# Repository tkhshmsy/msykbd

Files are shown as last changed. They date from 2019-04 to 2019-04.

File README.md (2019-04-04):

# msykbd

tkhshmsy's original keyboard which contains pcb, chassis, and firmware

## why build this?

I have been using [Logitech G13](https://support.logitech.com/en_us/product/g13-advanced-gameboard) which is very good and my favorite one.

With long use, it became not to working properly...
So, I want NEW one, but, unfortunately, G13 was already discontinued production.

I decided to make it myself.

## product

- Left-hand Gaming Keypad
  - 35 Keys
  - AnalogStick (work as keys, not pointing device)

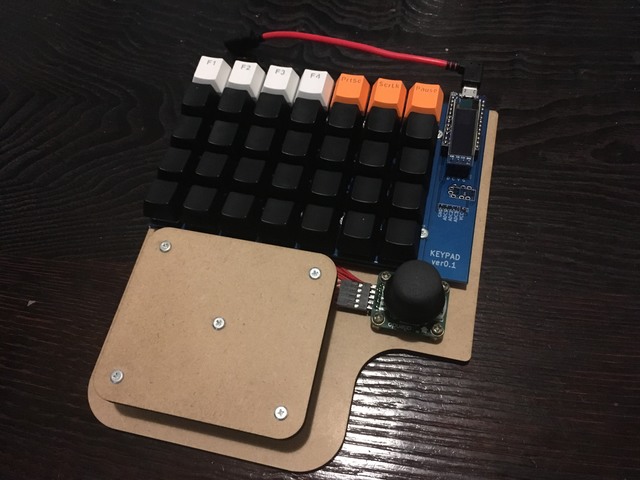
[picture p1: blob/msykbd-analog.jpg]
keypad


- Separate Ortholinear Keyboard
  - US 70 keys

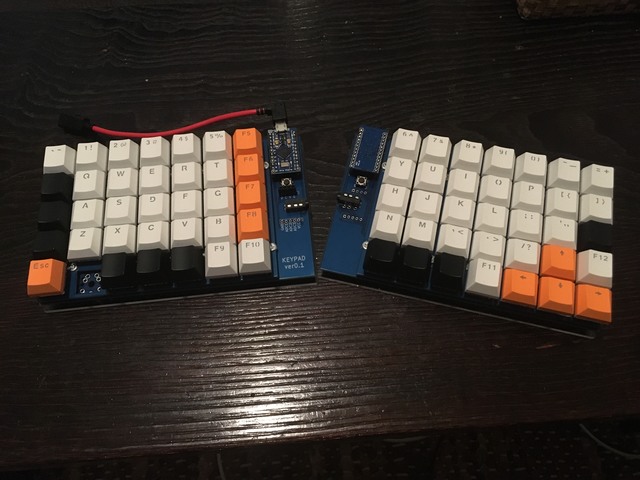
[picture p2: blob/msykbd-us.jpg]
uskbd

 
## PCB

- designed with Kicad v5

### parts

- promicro (ATMega32U4@16MHz)
- OLED (128x32 with SSD1306)
- mechanical key switches
  - cherryMX or Kailh Lowprofile
- TRRS plug
  
## Firmware

- build with platformio
  - framework : arduino

### required libraries

- ID 891
  - Keyboard
- ID 13
  - Adafruit GFX
- ID 135
  - Adafruit SSD1306

## Chassis

- designed with Fusion360
  - export DXF and convert into Adobe Illustrator
- for LaserCutter 'trotec Speedy 300'
  - worked at [FabLab Setagaya at IID](http://fablabsetagaya.com/)

## Author

- tkhshmsy@gmail.com

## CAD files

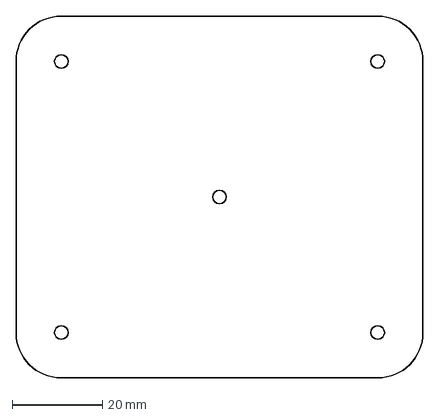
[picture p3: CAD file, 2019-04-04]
chassis/msykbd_parmrest_analog5x7.dxf
90.0 x 80.0 mm

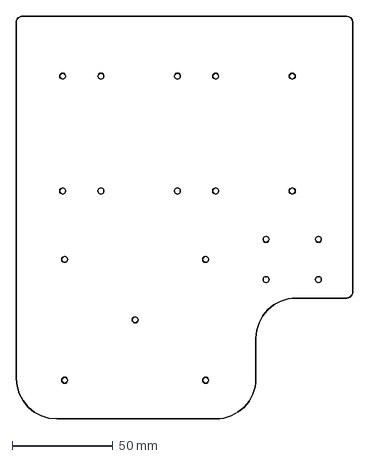
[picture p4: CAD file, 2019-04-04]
chassis/msykbd_analog5x7.dxf
167.0 x 200.0 mm

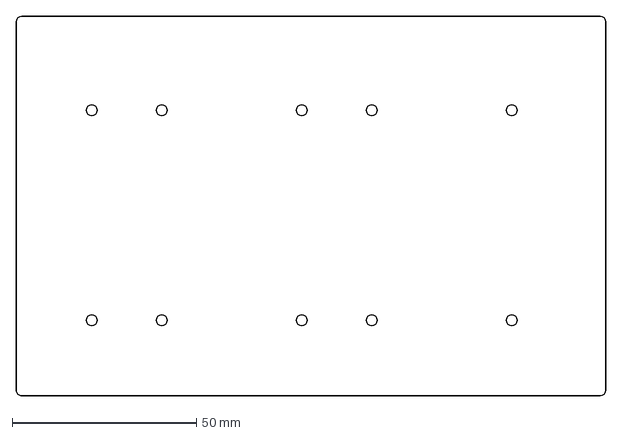
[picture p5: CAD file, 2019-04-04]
chassis/msykbd_base5x7.dxf
160.0 x 103.0 mm

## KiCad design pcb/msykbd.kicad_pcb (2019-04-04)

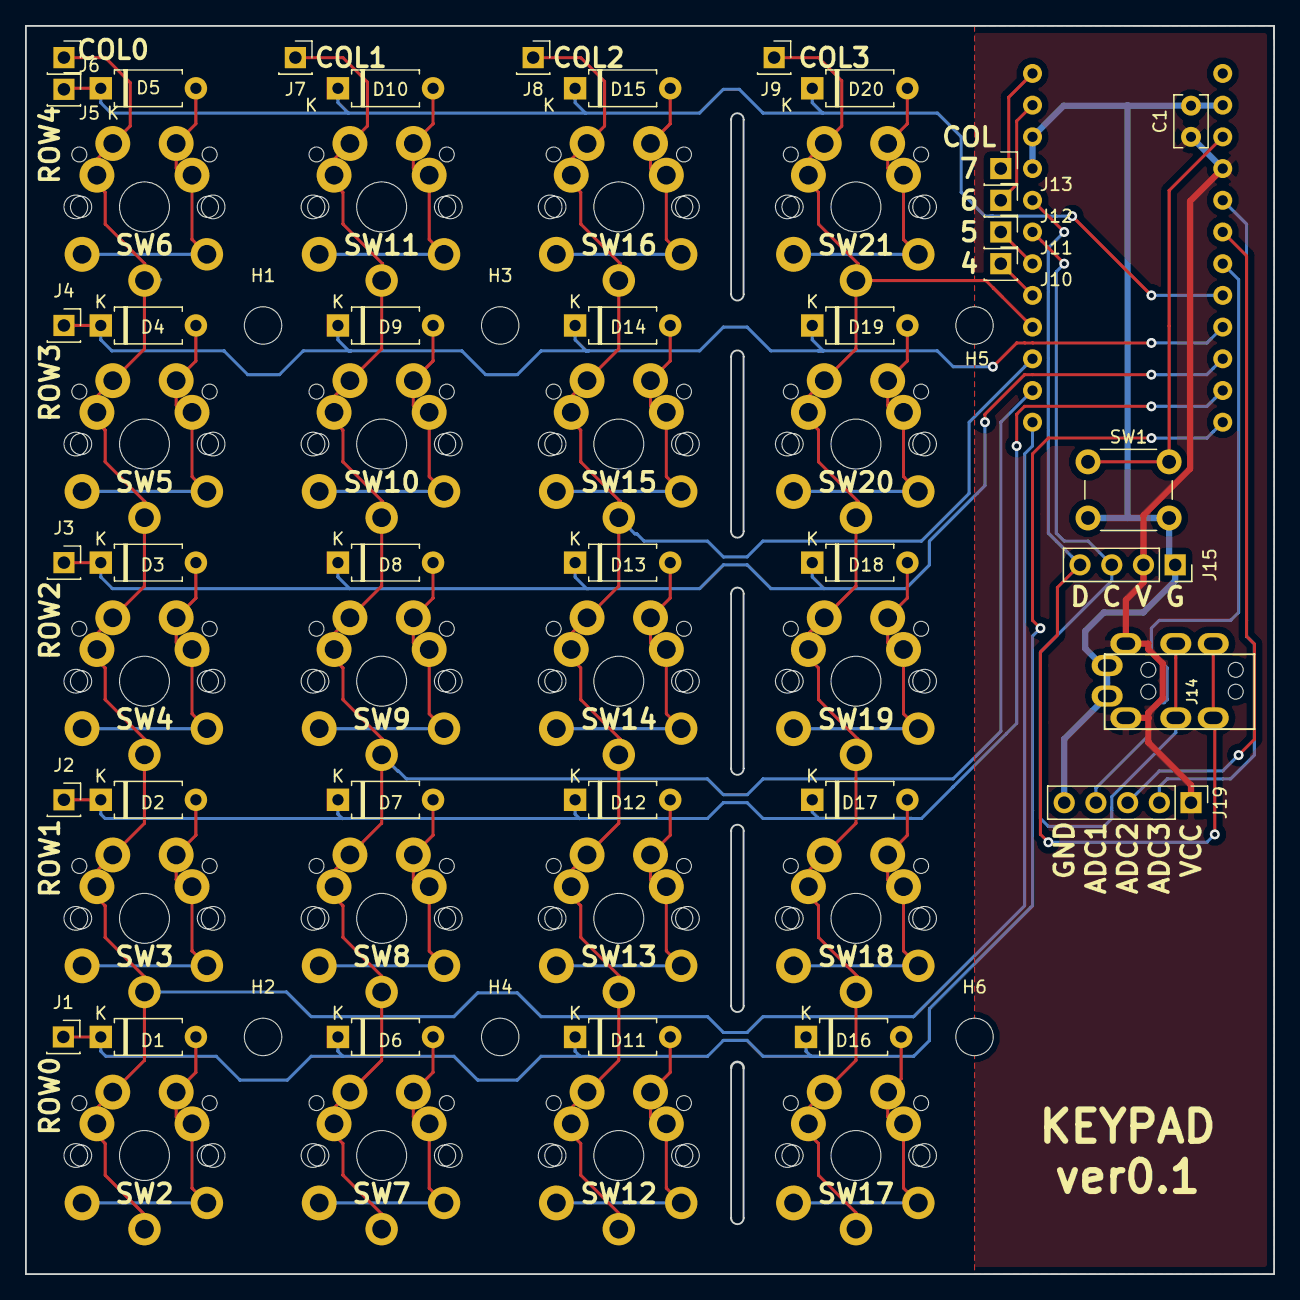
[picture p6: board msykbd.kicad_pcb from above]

Board: 2 copper layers, 100.0 x 100.0 mm, 65 parts (0 on the bottom side), 41 nets.

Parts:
C1: C_Small; C_Rect_L4.0mm_W2.5mm_P2.50mm
D1, D2, D3, D4, D5, D6, D7, D8, D9, D10, D11, D12, D13, D14, D15, D16, D17, D18, D19, D20: D; D_A-405_P7.62mm_Horizontal
H1, H2, H3, H4, H5, H6: MountingHole; MountingHole_3mm
J1, J2, J3, J4, J5, J6, J7, J8, J9, J10, J11, J12, J13: Conn_01x01; PinSocket_1x01_P2.54mm_Vertical
J14: MJ-4PP-9; MJ-4PP-9_rev2
J15: Conn_01x04; PinSocket_1x04_P2.54mm_Vertical
J19: Conn_01x05; PinHeader_1x05_P2.54mm_Vertical
SW1: SW_Push; SW_PUSH_6mm
SW2, SW3, SW4, SW5, SW6, SW7, SW8, SW9, SW10, SW11, SW12, SW13, SW14, SW15, SW16, SW17, SW18, SW19, SW20, SW21: SW_Push; MX_PG1350-Under_FLIP_HOLES_
U1: ProMicro; ProMicro_rev

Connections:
+5V: C1.1, J14.D, J15.2, J19.1, U1.21
/ADC1: J19.4, U1.18
/ADC2: J19.3, U1.19
/ADC3: J19.2, U1.20
/COL0: J6.1, SW2.1, SW3.1, SW4.1, SW5.1, SW6.1, U1.12
/COL1: J7.1, SW7.1, SW8.1, SW9.1, SW10.1, SW11.1, U1.11
/COL2: J8.1, SW12.1, SW13.1, SW14.1, SW15.1, SW16.1, U1.10
/COL3: J9.1, SW17.1, SW18.1, SW19.1, SW20.1, SW21.1, U1.9
/COL4: J10.1, U1.8
/COL5: J11.1, U1.7
/COL6: J12.1, U1.2
/COL7: J13.1, U1.1
/ROW0: D1.1, D6.1, D11.1, D16.1, J1.1, U1.13
/ROW1: D2.1, D7.1, D12.1, D17.1, J2.1, U1.14
/ROW2: D3.1, D8.1, D13.1, D18.1, J3.1, U1.15
/ROW3: D4.1, D9.1, D14.1, D19.1, J4.1, U1.16
/ROW4: D5.1, D10.1, D15.1, D20.1, J5.1, U1.17
/SCL: J14.C, J15.3, U1.6
/SDA: J14.B, J15.4, U1.5
/nRST: SW1.1, U1.22
GND: C1.2, J14.A, J15.1, J19.5, SW1.2, U1.3, U1.4, U1.23
unnamed: D1.2, SW2.2
unnamed: D2.2, SW3.2
unnamed: D3.2, SW4.2
unnamed: D4.2, SW5.2
unnamed: D5.2, SW6.2
unnamed: D6.2, SW7.2
unnamed: D7.2, SW8.2
unnamed: D8.2, SW9.2
unnamed: D9.2, SW10.2
unnamed: D10.2, SW11.2
unnamed: D11.2, SW12.2
unnamed: D12.2, SW13.2
unnamed: D13.2, SW14.2
unnamed: D14.2, SW15.2
unnamed: D15.2, SW16.2
unnamed: D16.2, SW17.2
unnamed: D17.2, SW18.2
unnamed: D18.2, SW19.2
unnamed: D19.2, SW20.2
unnamed: D20.2, SW21.2

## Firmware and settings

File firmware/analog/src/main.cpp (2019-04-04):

#include <Arduino.h>
#include <Keyboard.h>
#include <Wire.h>

#include "globals.h"
#include "keymatrix.h"
#include "oled.h"
#include "analogstick.h"

// #define FOR_DEBUG

KeyMatrix keyMatrix;
AnalogStick analogStick;
OLED oled;
uint8_t keyStates[COLUMNS];
int currentLayer = 1;
int nextLayer = 0;
int waitingLayer = nextLayer;
int waitingCounter = 0;

int rowPins[ROWS] = {
    18, 15, 14, 16, 10
};

int columnPins[COLUMNS] = {
    1, 6, 7, 8, 9, 5, 4, 0
};

uint8_t keyMap[LAYERS][ALLROWS][COLUMNS] = {
    { //defualt : PSO2
        {KC_DFLT,  KC_RAISE, KC_LOWER, KC_MEDIA, KC_PRSCN, KC_F1,    KC_F8,   KC_NONE}, 
        {KC_I,     KC_D,     KC_ESC,   KC_SPC,   KC_X,     KC_N,     KC_n8,   KC_NONE},
        {KC_U,     KC_R,     KC_LSHT,  KC_Q,     KC_E,     KC_ENTER, KC_n7,   KC_NONE},
        {KC_n9,    KC_n1,    KC_n2,    KC_n3,    KC_n4,    KC_n5,    KC_n6,   KC_NONE},
        {KC_G,     KC_B,     KC_F11,   KC_n0,    KC_F12,   KC_F5,    KC_F6,   KC_NONE},
        {KC_A,     KC_P,     KC_S,     KC_W,     KC_Z,     KC_NONE,  KC_NONE, KC_NONE}
    },
    { //raise
        {KC_DFLT,  KC_RAISE, KC_LOWER, KC_MEDIA, KC_PRSCN, KC_F1,    KC_F8,   KC_NONE}, 
        {KC_TAB,   KC_Q,    KC_W,    KC_E,    KC_R,   KC_T,     KC_NONE, KC_NONE},
        {KC_LCTR,  KC_A,    KC_S,    KC_D,    KC_F,   KC_G,     KC_NONE, KC_NONE},
        {KC_LSHT,  KC_Z,    KC_X,    KC_C,    KC_V,   KC_B,     KC_NONE, KC_NONE},
        {KC_RAISE, KC_NONE, KC_LALT, KC_LGUI, KC_SPC, KC_LOWER, KC_NONE, KC_NONE},
        {KC_A,     KC_D,    KC_S,    KC_W,    KC_Z,   KC_NONE,  KC_NONE, KC_NONE}
    },
    { //lower
        {KC_DFLT,  KC_RAISE, KC_LOWER, KC_MEDIA, KC_PRSCN, KC_F1,    KC_F8,   KC_NONE}, 
        {KC_TAB,   KC_Q,    KC_W,    KC_E,    KC_R,   KC_T,     KC_NONE, KC_NONE},
        {KC_LCTR,  KC_A,    KC_S,    KC_D,    KC_F,   KC_G,     KC_NONE, KC_NONE},
        {KC_LSHT,  KC_Z,    KC_X,    KC_C,    KC_V,   KC_B,     KC_NONE, KC_NONE},
        {KC_RAISE, KC_NONE, KC_LALT, KC_LGUI, KC_SPC, KC_LOWER, KC_NONE, KC_NONE},
        {KC_A,     KC_D,    KC_S,    KC_W,    KC_Z,   KC_NONE,  KC_NONE, KC_NONE}
    },
    { //media : Fusion360
        {KC_DFLT,  KC_RAISE, KC_LOWER, KC_MEDIA, KC_SCLCK, KC_F1,    KC_F8,   KC_NONE}, 
        {KC_TAB,   KC_Q,    KC_W,    KC_E,    KC_R,   KC_T,     KC_NONE, KC_NONE},
        {KC_LCTR,  KC_A,    KC_S,    KC_D,    KC_F,   KC_G,     KC_NONE, KC_NONE},
        {KC_LSHT,  KC_Z,    KC_X,    KC_C,    KC_V,   KC_B,     KC_NONE, KC_NONE},
        {KC_RAISE, KC_NONE, KC_LALT, KC_LGUI, KC_SPC, KC_LOWER, KC_NONE, KC_NONE},
        {KC_A,     KC_D,    KC_S,    KC_W,    KC_Z,   KC_NONE,  KC_NONE, KC_NONE}
    },
}; 

void setup()
{
    //setup serial
#ifdef FOR_DEBUG
    Serial.begin(38400);
    while(!Serial);
#endif

    //initialize
    keyMatrix.begin();
    analogStick.begin();
    oled.begin();
    delay(2000);
}

void dumpByte(uint8_t byte)
{
    for (int i = 0; i < 8; i++) {
        if (byte & 0x80) {
            Serial.print('1');
        } else {
            Serial.print('0');
        }
        byte = byte << 1;
    }
}

void dumpAllRows()
{
    Serial.print("M: ");
    for (int i = 0; i < ROWS; i++) {
        dumpByte(keyMatrix.getRow(i));
        Serial.print(", ");
    }
    Serial.print("A: ");
    dumpByte(keyMatrix.getRow(ROWS));
    Serial.println('e');
    Serial.println("----");
}

void keyPress(uint8_t keyCode, uint8_t state)
{
    if (state == ST_NOCHANGE) return;
    if (state == ST_RELEASE) {
        Keyboard.release(keyCode);
        return;
    }
    Keyboard.press(keyCode);
}

void loop()
{
    // own keyscan
    for (int i = 0; i < ROWS; i++) {
        keyMatrix.storeRow(i, keyMatrix.scanRow(i));
    }
    analogStick.scan();
    keyMatrix.storeRow(ROWS, analogStick.getRow());
    for (int i = 0; i < ALLROWS; i++) {
        if (i < ROWS) {
            keyMatrix.getRowState(i, keyStates);
        } else {
            analogStick.getState(keyStates);            
        }
        for (int j = 0; j < COLUMNS; j++) {
            uint8_t keyCode = keyMap[currentLayer][i][j];
            uint8_t state = keyStates[j];
            if (state != ST_NOCHANGE) {
                switch (keyCode) {
                    case KC_DFLT:
                        {
                            if (state == ST_PRESS) {
                                waitingLayer = LAYER_DEFAULT;
                            } else {
                                if (nextLayer != waitingLayer) {
                                    waitingLayer = nextLayer;
                                }
                            }
                        }
                        break;
                    case KC_RAISE:
                        {
                            if (state == ST_PRESS) {
                                waitingLayer = LAYER_RAISE;
                            } else {
                                if (nextLayer != waitingLayer) {
                                    waitingLayer = nextLayer;
                                }
                            }
                        }
                        break;
                    case KC_LOWER:
                        {
                            if (state == ST_PRESS) {
                                waitingLayer = LAYER_LOWER;
                            } else {
                                if (nextLayer != waitingLayer) {
                                    waitingLayer = nextLayer;
                                }
                            }
                        }
                        break;
                    case KC_MEDIA:
                        {
                            if (state == ST_PRESS) {
                                waitingLayer = LAYER_MEDIA;
                            } else {
                                if (nextLayer != waitingLayer) {
                                    waitingLayer = nextLayer;
                                }
                            }
                        }
                        break;
                    case KC_NONE:
                        //no effect
                        break;
                    default:
                        keyPress(keyCode, state);
                        break;
                }
            }
        }
    }
    //Change Layer with long push
    if (nextLayer != waitingLayer) {
        if (waitingCounter > 300) {
            nextLayer = waitingLayer;
            waitingCounter = 0;
        }
        waitingCounter++;
    } else {
        waitingCounter = 0;
    }

    // Change Layer
    if (currentLayer != nextLayer) {
        currentLayer = nextLayer;
        oled.clear();
        oled.printLayer(currentLayer);
    }
#ifdef FOR_DEBUG
    //DEBUG: keymatrix
    static int c = 0;
    if ( c % 20 == 0) {
        dumpAllRows();
    }
    c++;
#endif
    keyMatrix.swapBuffers();
    analogStick.swapBuffers();
    delay(10);
}

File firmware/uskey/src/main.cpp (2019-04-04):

#include <Arduino.h>
#include <Keyboard.h>
#include <Wire.h>

#include "globals.h"
#include "oled.h"
#include "keymatrix.h"

#define MASTER_LEFT
// #define FOR_DEBUG
OLED oled;
KeyMatrix keyMatrix;
uint8_t keyStates[COLUMNS];
int currentLayer = 1;
int nextLayer = 0;

int rowPins[ROWS] = {
    18, 15, 14, 16, 10
};

int columnPins[COLUMNS] = {
#ifdef MASTER_LEFT
    1, 6, 7, 8, 9, 5, 4, 0
#else
    1, 0, 4, 5, 9, 8, 7, 6
#endif
};

uint8_t analogKeyMap[5] = {
    KC_A, KC_D, KC_W, KC_S, KC_Z
};

uint8_t keyMap[LAYERS][ALLROWS][COLUMNS] = {
    { //defualt
        {KC_ESC,   KC_n1,   KC_n2,   KC_n3,   KC_n4,  KC_n5,    KC_BQT,   KC_NONE}, 
        {KC_TAB,   KC_Q,    KC_W,    KC_E,    KC_R,   KC_T,     KC_NONE,  KC_NONE},
        {KC_LCTR,  KC_A,    KC_S,    KC_D,    KC_F,   KC_G,     KC_NONE,  KC_NONE},
        {KC_LSHT,  KC_Z,    KC_X,    KC_C,    KC_V,   KC_B,     KC_NONE,  KC_NONE},
        {KC_RAISE, KC_NONE, KC_LALT, KC_LGUI, KC_SPC, KC_LOWER, KC_ENTER, KC_NONE},

        {KC_n6,  KC_n7,   KC_n8,   KC_n9,   KC_n0,   KC_HYP,  KC_EQL,   KC_NONE},
        {KC_Y,   KC_U,    KC_I,    KC_O,    KC_P,    KC_LBRK, KC_RBRK,  KC_NONE},
        {KC_H,   KC_J,    KC_K,    KC_L,    KC_SCLN, KC_SQT,  KC_ENTER, KC_NONE},
        {KC_N,   KC_M,    KC_CMMA, KC_PRD,  KC_SLH,  KC_UP,   KC_RAISE, KC_NONE},
        {KC_SPC, KC_RGUI, KC_RALT, KC_DEL,  KC_LEFT, KC_DOWN, KC_RIGHT, KC_NONE}
    },
    { //raise
        {KC_ESC,   KC_F1,   KC_F2,   KC_F3,   KC_F4,  KC_F5,    KC_BQT,   KC_NONE}, 
        {KC_TAB,   KC_Q,    KC_W,    KC_E,    KC_R,   KC_T,     KC_NONE,  KC_NONE},
        {KC_LCTR,  KC_A,    KC_S,    KC_D,    KC_F,   KC_G,     KC_NONE,  KC_NONE},
        {KC_LSHT,  KC_Z,    KC_X,    KC_C,    KC_V,   KC_B,     KC_NONE,  KC_NONE},
        {KC_RAISE, KC_NONE, KC_LALT, KC_LGUI, KC_SPC, KC_LOWER, KC_ENTER, KC_NONE},

        {KC_F6,  KC_F7,   KC_F8,   KC_F9,   KC_F10,   KC_F11,  KC_F12,   KC_NONE},
        {KC_Y,   KC_U,    KC_I,    KC_O,    KC_PRSCN, KC_DEL,  KC_BS,    KC_NONE},
        {KC_H,   KC_J,    KC_K,    KC_L,    KC_SCLN,  KC_SQT,  KC_ENTER, KC_NONE},
        {KC_N,   KC_M,    KC_CMMA, KC_PRD,  KC_BSLH,  KC_PGUP, KC_RAISE, KC_NONE},
        {KC_SPC, KC_RGUI, KC_RALT, KC_RCTR, KC_HOME,  KC_PGDN, KC_END,   KC_NONE}
    },
    { //lower
        {KC_ESC,   KC_n1,   KC_n2,   KC_n3,   KC_n4,  KC_n5,    KC_BQT,   KC_NONE}, 
        {KC_TAB,   KC_Q,    KC_W,    KC_E,    KC_R,   KC_T,     KC_NONE,  KC_NONE},
        {KC_LCTR,  KC_A,    KC_S,    KC_D,    KC_F,   KC_G,     KC_NONE,  KC_NONE},
        {KC_LSHT,  KC_Z,    KC_X,    KC_C,    KC_V,   KC_B,     KC_NONE,  KC_NONE},
        {KC_RAISE, KC_NONE, KC_LALT, KC_LGUI, KC_SPC, KC_LOWER, KC_ENTER, KC_NONE},

        {KC_n6,  KC_n7,   KC_n8,   KC_n9,   KC_n0,   KC_HYP,  KC_EQL,   KC_NONE},
        {KC_Y,   KC_U,    KC_I,    KC_O,    KC_P,    KC_LBRK, KC_RBRK,  KC_NONE},
        {KC_H,   KC_J,    KC_K,    KC_L,    KC_SCLN, KC_SQT,  KC_ENTER, KC_NONE},
        {KC_N,   KC_M,    KC_CMMA, KC_PRD,  KC_BSLH, KC_VLUP, KC_RAISE, KC_NONE},
        {KC_SPC, KC_RGUI, KC_RALT, KC_RCTR, KC_BLDN, KC_VLDN, KC_BLUP,  KC_NONE}
    },
}; 

#ifdef MASTER_LEFT
#else
void wireRequest()
{
    Wire.write(keyMatrix.getRow(0));
    Wire.write(keyMatrix.getRow(1));
    Wire.write(keyMatrix.getRow(2));
    Wire.write(keyMatrix.getRow(3));
    Wire.write(keyMatrix.getRow(4));
}
#endif

void setup()
{
    //setup serial
    Serial.begin(38400);
#ifdef FOR_DEBUG
   while(!Serial);
#endif

    //initialize
    keyMatrix.begin();
#ifdef MASTER_LEFT
    Keyboard.begin();
    // Wire.begin();
    oled.begin();
    delay(3000);
#else
    Wire.begin(I2CADDR_SLAVE);
    Wire.onRequest(wireRequest);
#endif
}

void dumpByte(uint8_t byte)
{
    for (int i = 0; i < 8; i++) {
        if (byte & 0x80) {
            Serial.print('1');
        } else {
            Serial.print('0');
        }
        byte = byte << 1;
    }
}

void dumpAllRows()
{
    Serial.print("M: ");
    for (int i = 0; i < ROWS; i++) {
        dumpByte(keyMatrix.getRow(i));
        Serial.print(", ");
    }
#ifdef MASTER_LEFT
    Serial.println('e');
    Serial.print("S: ");
    for (int i = ROWS; i < ALLROWS; i++) {
        dumpByte(keyMatrix.getRow(i));
        Serial.print(", ");
    }
#endif
    Serial.println('e');
    Serial.println("----");
}

#ifdef MASTER_LEFT
void keyPress(uint8_t keyCode, uint8_t state)
{
    if (state == ST_NOCHANGE) return;
    if (state == ST_RELEASE) {
        Keyboard.release(keyCode);
        return;
    }
    Keyboard.press(keyCode);
}
#endif

void loop()
{
    // own keyscan
    for (int i = 0; i < ROWS; i++) {
        keyMatrix.storeRow(i, keyMatrix.scanRow(i));
    }
#ifdef MASTER_LEFT
    Wire.requestFrom(I2CADDR_SLAVE, 5);
    for (int i = 0; i < ROWS; i++) {
        while (!Wire.available());
        keyMatrix.storeRow(ROWS + i, Wire.read());
    }    
#else
#endif

#ifdef MASTER_LEFT
    // main sequence
    for (int i = 0; i < ALLROWS; i++) {
        keyMatrix.getRowState(i, keyStates);
        for (int j = 0; j < COLUMNS; j++) {
            uint8_t keyCode = keyMap[currentLayer][i][j];
            uint8_t state = keyStates[j];
            if (state != ST_NOCHANGE) {
                switch (keyCode) {
                    case KC_RAISE:
                        {
                            if (state == ST_PRESS) {
                                nextLayer = LAYER_RAISE;
                            } else {
                                nextLayer = LAYER_DEFAULT;
                            }
                        }
                        break;
                    case KC_LOWER:
                        {
                            if (state == ST_PRESS) {
                                nextLayer = LAYER_LOWER;
                            } else {
                                nextLayer = LAYER_DEFAULT;
                            }
                        }
                        break;
                    case KC_NONE:
                        //no effect
                        break;
                    default:
                        keyPress(keyCode, state);
                        break;
                }
            }
        }
    }

    // Change Layer
    if (currentLayer != nextLayer) {
        currentLayer = nextLayer;
        oled.clear();
        oled.printLayer(currentLayer);
    }
#endif
#ifdef FOR_DEBUG
    //DEBUG: keymatrix
    static int c = 0;
    if ( c % 20 == 0) {
        dumpAllRows();
    }
    c++;
#endif
    keyMatrix.swapBuffers();
    delay(10);
}
